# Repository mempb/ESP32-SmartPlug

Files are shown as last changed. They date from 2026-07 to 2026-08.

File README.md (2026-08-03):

# ESP32-C3 HomeKit Smart Plug

A standalone WiFi smart plug built around the ESP32-C3 Super Mini, exposing native Apple HomeKit control via [esp-homekit-sdk](https://github.com/espressif/esp-homekit-sdk).

## Overview

The ESP32-C3 connects directly to the home WiFi network and implements the HomeKit Accessory Protocol (HAP) on-device using Espressif's open-source `esp-homekit-sdk`. It advertises itself as a HomeKit accessory and pairs directly with the Apple Home app. A relay switches mains power to a connected load (tested with a small AC fan), with a local status LED and a manual push-button override.

## Hardware

- **MCU:** ESP32-C3 Super Mini (WiFi + BLE)
- **Relay:** Songle SRD-05VDC-SL-C
- **Relay drive:** 2N3904 NPN, low-side switched, 1k base resistor, 1N4007 flyback diode across the coil
- **Mains supply:** Hi-Link HLK-PM01 (AC → 5V)
- **I/O:** status LED, manual push-button (SW2)
- **Connectors:** 5.08mm pitch screw terminals for mains in/out
- Custom PCB (KiCad), hand-solderable THT components throughout

## Firmware

- **Toolchain:** PlatformIO, `framework = espidf`
- **Application logic:** plain ESP-IDF C — GPIO config, debounced button input, LED/relay control
- **HomeKit layer:** `esp-homekit-sdk` (Espressif's open-source HAP implementation), added as an ESP-IDF component
- WiFi credentials configured via `idf.py menuconfig` (hardcoded); HomeKit pairing done separately after WiFi connects via the HomeKit setup code

## Setup

- `git clone --recursive git@github.com:mempb/ESP32-SmartPlug.git`
- Install `PlatformIO` VSCode extension
- WiFi SSID & password: 
    - Option A: `pio run -t menuconfig` → App Wi-Fi → Source of Wi-Fi Credentials → Use Hardcoded → set SSID and password
    - Option B: edit `sdkconfig.esp32-c3-devkitm-1`:
      - `CONFIG_APP_WIFI_SSID="SSID"`
      - `CONFIG_APP_WIFI_PASSWORD="pass"`
- Build/flash: `pio run -t upload -t monitor`

## Roadmap

- [x] Schematic design
- [x] PCB layout and routing, order
- [x] PCB assembly (hand soldering)
- [X] GPIO firmware: button input, debounce, LED toggle
- [X] HomeKit firmware (esp-homekit-sdk integration, relay control, button + LED sync)
- [X] Respin PCB, order (smaller form factor, fix missing GND trace, add capacitor)
- [ ] Enclosure design/print
- [ ] Final writeup: build photos, schematics, wiring diagram, etc

## Repo Structure

```
/components esp-homekit-sdk location
/pcb        KiCad project
/src        ESP-IDF source
/docs       Schematics, pictures, etc. (TODO)
/housing    3D print housing design (TODO)
```

## References

- https://docs.espressif.com/projects/esp-idf/en/stable/esp32/index.html
- https://github.com/espressif/esp-homekit-sdk

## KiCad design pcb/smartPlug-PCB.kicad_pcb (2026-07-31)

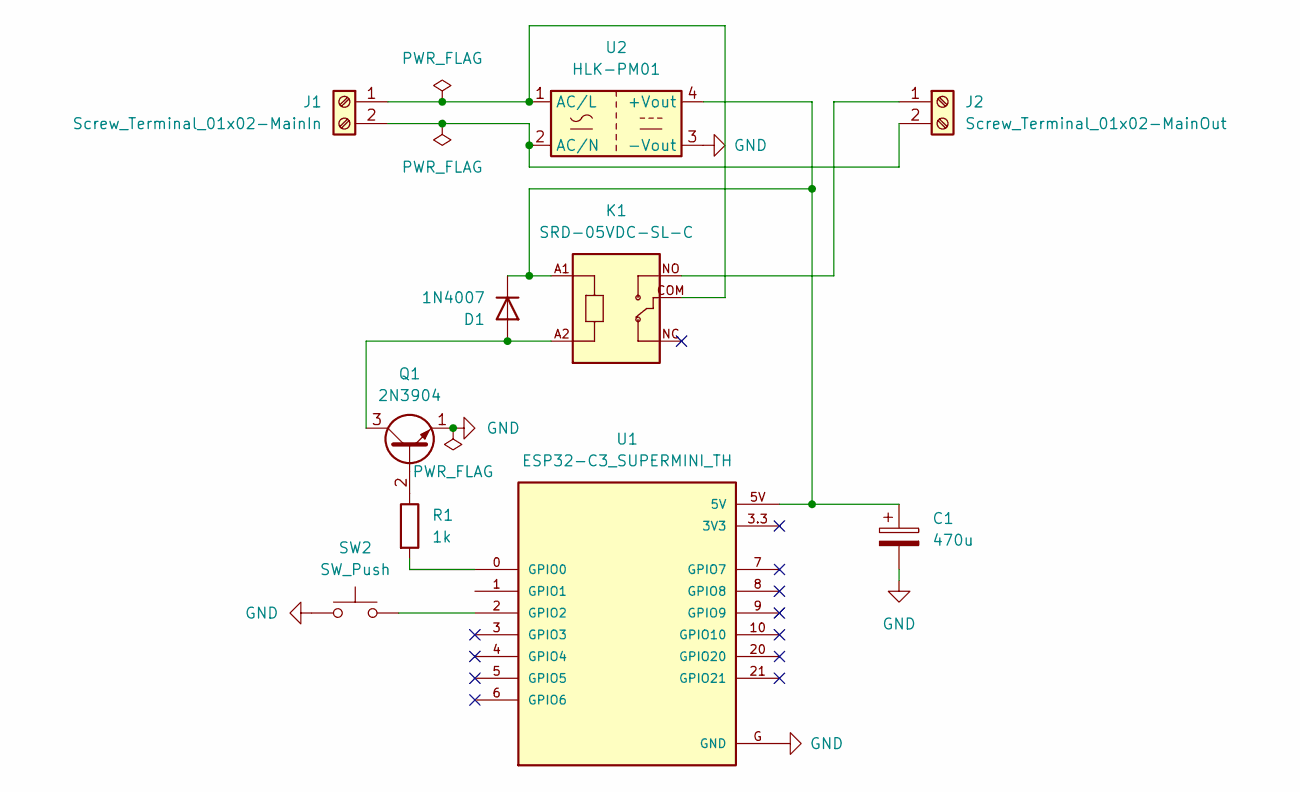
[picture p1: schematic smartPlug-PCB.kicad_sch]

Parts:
C1: 470u; CP_Radial_D8.0mm_P3.50mm
D1: 1N4007; D_DO-41_SOD81_P10.16mm_Horizontal
J1: Screw_Terminal_01x02-MainIn; TerminalBlock_Phoenix_MKDS-1,5-2-5.08_1x02_P5.08mm_Horizont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
J2: Screw_Terminal_01x02-MainOut; TerminalBlock_Phoenix_MKDS-1,5-2-5.08_1x02_P5.08mm_Horizont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
K1: SRD-05VDC-SL-C; RELAY_SRD-05VDC-SL-C
Q1: 2N3904; TO-92_Inline
R1: 1k; R_Axial_DIN0207_L6.3mm_D2.5mm_P10.16mm_Horizontal
SW2: SW_Push; SW_PUSH_6mm
U1: ESP32-C3_SUPERMINI_TH; MODULE_ESP32-C3_SUPERMINI_TH
U2: HLK-PM01; Converter_ACDC_Hi-Link_HLK-PMxx

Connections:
GND: C1.2, Q1.1 (E), SW2.1, U1.G (GND), U2.3 (-Vout)
unnamed: D1.2 (A), K1.A2, Q1.3 (C)
unnamed: C1.1, D1.1 (K), K1.A1, U1.5V, U2.4 (+Vout)
unnamed: J1.1, K1.COM, U2.1 (AC/L)
unnamed: J1.2, J2.2, U2.2 (AC/N)
unnamed: J2.1, K1.NO
unnamed: Q1.2 (B), R1.1
unnamed: R1.2, U1.0 (GPIO0)
unnamed: SW2.2, U1.2 (GPIO2)

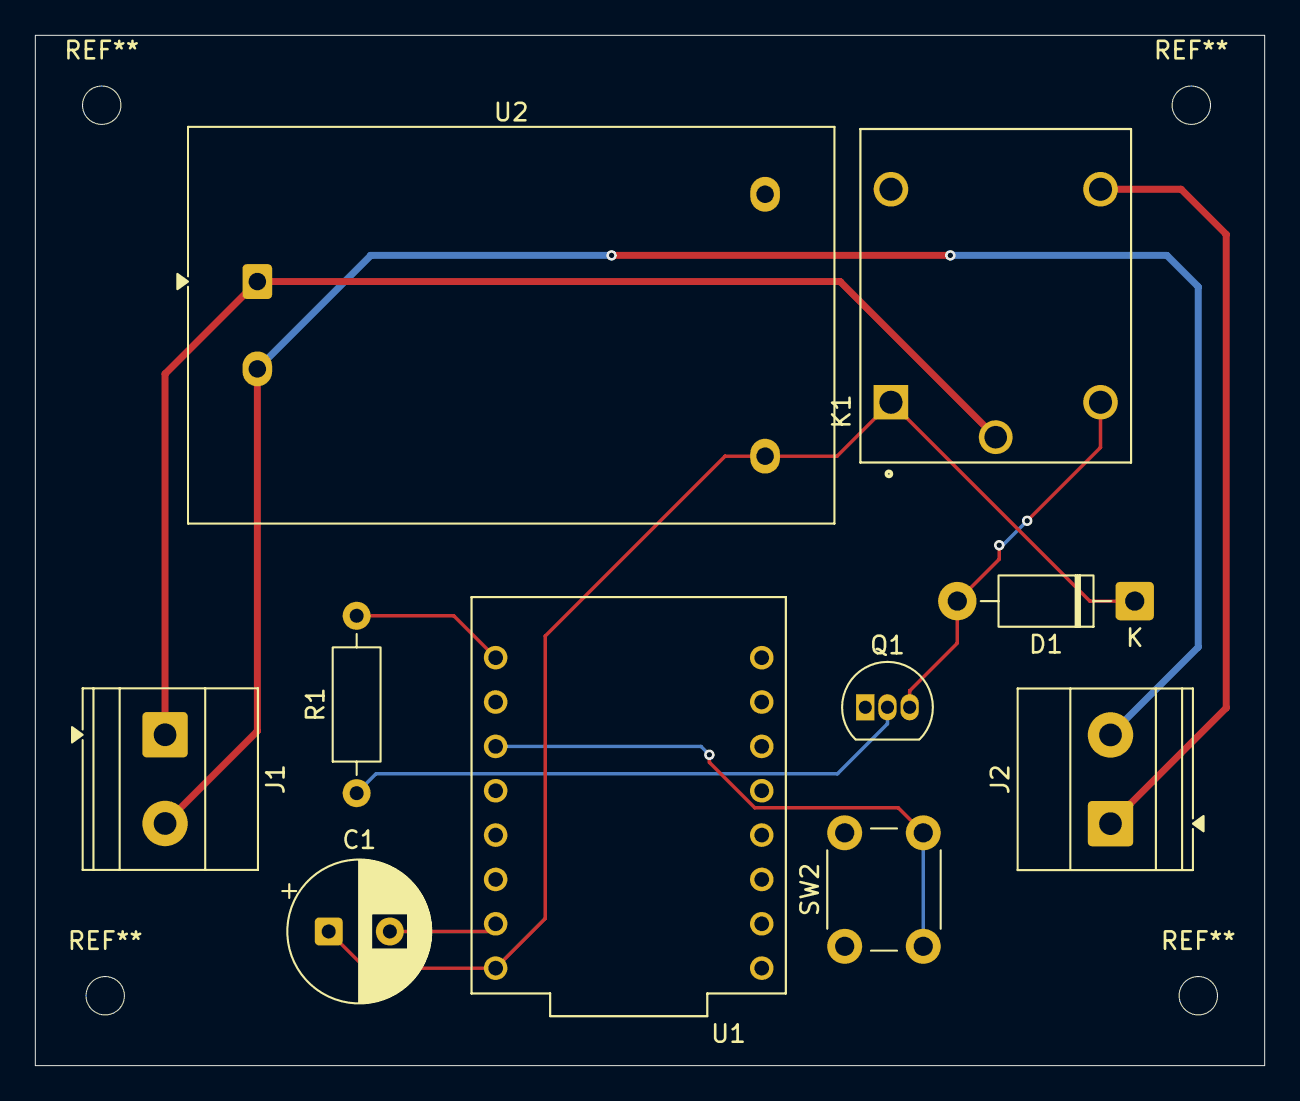
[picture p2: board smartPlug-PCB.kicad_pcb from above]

Board: 2 copper layers, 70.4 x 59.0 mm, 10 parts (0 on the bottom side), 9 nets.

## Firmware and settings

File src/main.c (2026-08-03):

#include "driver/gpio.h"
#include "esp_log.h"
#include "esp_timer.h"
#include "freertos/FreeRTOS.h"
#include "freertos/task.h"
#include "nvs_flash.h"
#include "homekit.h"

#define RELAY_PIN   0
#define BTN_PIN     2
#define LED_PIN     8       // ESP32-C3 onboard LED
#define DEBOUNCE_US 20000

void init()
{
    // === Init GPIOs === //
    // Relay
    gpio_set_direction(RELAY_PIN, GPIO_MODE_OUTPUT);
    // LED
    gpio_set_direction(LED_PIN, GPIO_MODE_OUTPUT);
    // Button
    gpio_set_direction(BTN_PIN, GPIO_MODE_INPUT);
    gpio_set_pull_mode(BTN_PIN, GPIO_PULLUP_ONLY);

    // === Init Homekit === //
    homekit_start();
}

// pass 0 for LED off / relay closed, 1 for LED on / relay open
void setIO(bool state)
{
    gpio_set_level(RELAY_PIN, state);
    gpio_set_level(LED_PIN, !state);    // onboard LED inverted
}

// returns the toggled plug state
int checkBtnWithDebounce(int state)
{
    static int lastRawReading      = 0;        // last raw pin read
    static int debouncedState      = 0;        // confirmed, stable state
    static int64_t lastChangeTime  = 0;        // when raw reading last changed

    int rawReading = gpio_get_level(BTN_PIN);

    if (rawReading != lastRawReading)
    {
        lastChangeTime = esp_timer_get_time();
        lastRawReading = rawReading;
    }
    if ((esp_timer_get_time() - lastChangeTime) > DEBOUNCE_US)
    {
        if (rawReading != debouncedState)
        {
            debouncedState = rawReading;

            // Only toggle on the press edge (0 -> 1), not release
            if (debouncedState == 1)
            {
                state = !state;
                return state;
            }
        }
    }
    return state;
}

void app_main(void)
{
    init();

    int plugState = 0;
    plug_set(plugState);    // Start with LED off / relay open

    while (1)
    {
        if (checkBtnWithDebounce(plugState) != plugState)
        {
            plugState = !plugState;
            plug_set(plugState);
        }
        vTaskDelay(pdMS_TO_TICKS(20));
    }
}

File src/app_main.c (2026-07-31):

#include <stdio.h>
#include "driver/gpio.h"
#include "esp_log.h"
#include "esp_timer.h"
#include "freertos/FreeRTOS.h"
#include "freertos/task.h"
#include "homekit.h"

#define RELAY_PIN   0
#define LED_PIN     1
#define BTN_PIN     2
#define DEBOUNCE_US 20000

static const char *TAG = "smartplug";

void init()
{
    // Relay
    gpio_set_direction(RELAY_PIN, GPIO_MODE_OUTPUT);

    // LED
    gpio_set_direction(LED_PIN, GPIO_MODE_OUTPUT);

    // Button
    gpio_set_direction(BTN_PIN, GPIO_MODE_INPUT);
    gpio_set_pull_mode(BTN_PIN, GPIO_PULLUP_ONLY);
}

// pass 0 for LED off
// pass 1 for LED on
void setLED(int led)
{
    gpio_set_level(LED_PIN, led);
}

// pass 0 for relay open
// pass 1 for relay closed
void setRelay(int relay)
{
    gpio_set_level(RELAY_PIN, relay);
}

// return 0 if button not pressed
// return 1 if button pressed
int checkBtn()
{
    int btnState = gpio_get_level(BTN_PIN);

    if (!btnState)
    {
        ESP_LOGI(TAG, "button pressed");
        return 1;
    }
    else
    {
        return 0;
    }
}

void app_main(void)
{
    init();

    int state = 0;
    setLED(state);   // Start with LED off
    setRelay(state); // Start with relay open

    int lastRawReading = 0;      // last raw pin read
    int debouncedState = 0;      // confirmed, stable state
    int64_t lastChangeTime = 0;  // when raw reading last changed

    while (1)
    {
        int rawReading = checkBtn();  // read ONCE per loop

        if (rawReading != lastRawReading)
        {
            lastChangeTime = esp_timer_get_time();
            lastRawReading = rawReading;
        }

        if ((esp_timer_get_time() - lastChangeTime) > DEBOUNCE_US)
        {
            if (rawReading != debouncedState)
            {
                debouncedState = rawReading;

                // Only toggle on the press edge (0 -> 1), not release
                if (debouncedState == 1)
                {
                    state = !state;
                    setLED(state);      // LED toggle
                    setRelay(state);    // Relay toggle
                    ESP_LOGI(TAG, "toggled, state=%d", state);
                }
            }
        }

        vTaskDelay(pdMS_TO_TICKS(5));
    }
}

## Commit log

2026-07-13 Initial commit. PCB done.
    [smartPlug-PCB-B_Cu.gbr, smartPlug-PCB-B_Mask.gbr, smartPlug-PCB-B_Paste.gbr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]
2026-07-13 Added M3 scre holes to PCB
    [smartPlug-PCB-B_Cu.gbr, smartPlug-PCB-B_Mask.gbr, smartPlug-PCB-B_Paste.gbr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]
2026-07-31 Restructure repo, implemented LED toggling, tested on PCB
    [smartPlug-PCB-B_Cu.gbr, smartPlug-PCB-B_Mask.gbr, smartPlug-PCB-B_Paste.gbr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]
2026-07-31 Added relay toggling, tested. Added a missing ground trace to PCB, regenereated gerbers.
    [smartPlug-PCB-B_Cu.gbr, smartPlug-PCB-B_Mask.gbr, smartPlug-PCB-B_Paste.gbr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]
2026-07-31 Remove stray root esp-homekit-sdk clone and untrack pcb/.history
2026-07-31 Homekit implemented
    [partitions.csv]
2026-07-31 Respun PCB. Replaced LED with onboard LED in FW.
    [smartPlug-PCB-B_Cu.gbr, smartPlug-PCB-B_Mask.gbr, smartPlug-PCB-B_Paste.gbr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]
2026-08-03 Code cleanup. Added HomeKit updating when manual button toggles
